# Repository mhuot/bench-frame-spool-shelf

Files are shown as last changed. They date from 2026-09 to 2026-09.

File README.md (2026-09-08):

# Bench Frame Spool Shelf

**[Project site &rarr; mhuot.github.io/bench-frame-spool-shelf](https://mhuot.github.io/bench-frame-spool-shelf/)**

Filament spool storage that hangs on the slotted uprights of a steel bench
frame. Mine is an Ergotron LAN Organizer 3000. Two printed brackets hook
into the slotted DuraFrame uprights and carry two parallel rods. Spools rest in the valley between the rods. Lift one straight out,
drop the next one in, nothing else moves. A spool in the cradle rolls
freely, so it feeds without a fight. No drilling and no hardware. The
brackets hook in the same way Ergotron's own shelves do.

The rods are 1" schedule 40 PVC by default. Wooden dowels, aluminium pipe
and conduit all work too. More on that below.

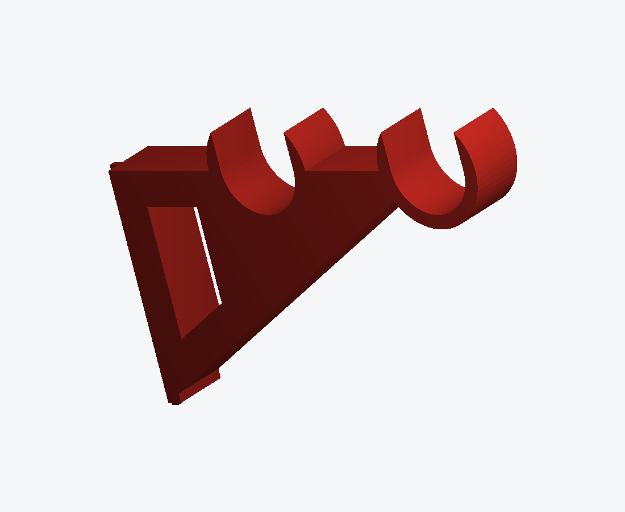
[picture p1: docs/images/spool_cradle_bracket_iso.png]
Spool cradle bracket


## The desk

In the 1990s it felt like every NOC and data center, at least the ones near
me, had furniture from [Ergotron](https://www.ergotron.com/) in
[Eagan, Minnesota](https://en.wikipedia.org/wiki/Eagan,_Minnesota). The desks
matched the look those rooms had and the job they did.

The one I have sat in a data center with a row of computers on it. They ran
the small ISP my employer operated. I picked it up when the company
liquidated, after they were no more. The slotted uprights are the same ones
that held their shelves, which is why nothing here needs a drill.

## Parts

| File | What it is |
|---|---|
| `exports/slot_gauge.stl` | **Print this first.** Just the hook plate. It tells you whether the hooks fit your upright before you spend four hours on a bracket. |
| `exports/saddle_coupon.stl` | **Print this second.** An 8 mm slice of the arm tip with both rod pockets. Drop your actual rod in and see if it seats. About 12 cm³. |
| `exports/spool_cradle_bracket.stl` | The bracket. Two per shelf level. It is symmetric, so there is no left or right. |
| `exports/rod_end_cap.stl` | Press-fit cap for the rod ends. The 42 mm flange stops a rod walking out of its saddle, and four crush ribs on the 24 mm stem grip the pipe bore. Sized for a bore I measured at 30 mm. The schedule 40 spec says 26.6 and was wrong for my pipe. Measure yours, set `PIPE_INNER_DIAMETER` in `scripts/build_rod_end_cap.py`, and print one before printing four per level. Flange down, no supports. |
| `exports/rod_label_clip.stl` | Snap-on label clip. A C-ring snaps onto a rod from below and slides along to sit under its spool. The 58 x 29 mm face takes a 1" x 2-1/8" adhesive label and hangs just past plumb, aimed at someone looking up at a rod above their head. That is `PADDLE_ANGLE_DEG = 100`. A shelf below eye level wants about 50. The face is flush with one side of the 20 mm ring, and the ring is that wide so the offset label does not cock the clip on the rod. One per spool, printed on the flat side (rotate 90° about X), no supports. Eight fit a MINI bed. |
| `cad/*.step`, `cad/*.f3d` | The same parts as CAD, written by the same build run as the STLs. |

## Check the fit before printing brackets

I measured the slots by hand. 3/4" tall, 1" vertical pitch, about 1/8"
wide. Each upright has one column of slots. The double track at the
middle of a 60" module is just the two joined frames' columns sitting side
by side. So the bracket hooks one column with a single centred blade
column, four rows tall, and mounts on any upright.

The first gauge pinched before it seated. Paint and the burr on a punched
slot are worth a millimetre no drawing mentions. The throat went from 2.8
to 3.8 mm, the lips got lead-in chamfers, and the second gauge sat flush.
Your uprights may differ from mine, so the gauge is still the first thing
to print.

1. Print `slot_gauge.stl` flat on its side and hook it into the upright.
   The blades should enter the slots, drop about 14 mm and sit flush with
   no rock. If it binds or rattles, edit `SLOT_WIDTH` or
   `FACE_METAL_THICKNESS` at the top of `scripts/build_rod_bracket.py`,
   rebuild, print again.
2. Print `saddle_coupon.stl` and drop your rod stock into both pockets. It
   should seat fully and lift out without force. If not, adjust
   `ROD_OUTER_DIAMETER` or `SADDLE_CLEARANCE`.
3. When both pass, print two brackets.

## Geometry

- The rod axes sit 70 mm and 150 mm out from the upright face, at the same
  height. A 200 mm spool resting on both rods touches them about 20°
  either side of plumb. Deep enough that it stays put, shallow enough to
  lift out one-handed. The back of the spool clears the upright by about
  10 mm.
- A resting spool's top sits about 285 mm above the bracket's bottom edge.
  Leave 12" of frame above the mounting slots.
- On the 30" DuraFrame (10-063-100) the upright centres are about 28"
  apart. Cut rods to 29.5" (750 mm) so they span both saddles fully.
- Nothing holds the rods down, because nothing ever pulls them up. Spools
  press them into the saddles and get lifted off, never with them.
  Sideways is a different story. That is what the end caps are for. Their
  crush ribs grip the bore and the flange is wider than the saddle, so a
  rod cannot walk out while you shove spools around. No glue.
- The bracket is 24 mm wide, narrower than the 1" gap between the two
  slot columns at the module centre, so both bays can carry cradles at the
  same height without the middle brackets colliding.

## Rods, sag and cost

One level holds about 12 kg. That is two brackets at about 6 kg each with
roughly 2x structural margin, so a full row of nine 1 kg spools, or count
3 kg spools by weight. Rod strength is never the limit. PVC runs at about
2 MPa against a 50 MPa allowable. Stiffness is the limit, because a rod
that sags forms a shallow valley and the spools slowly roll toward the
middle of it.

Sag below is per rod at full load, about 5.6 kg over the 711 mm span. Cost
is per level, two 29.5" rods, Home Depot, September 2026.

| Rod | Sag | Fits the stock 34.2 mm pocket? | Cost per level |
|---|---|---|---|
| 1" sch 40 PVC (default) | ~2.4 mm, creeping to 4-6 mm over months | yes | ~$5 (10 ft makes 4 rods) |
| 1" sch 40 aluminium pipe | ~0.1 mm, no creep | yes, same 33.4 mm OD as PVC | ~$32 ($48 for 8 ft, 3 rods) |
| 1-1/4" hardwood dowel | ~0.4 mm | close, 2.5 mm of play, fine | ~$10 |
| 1" hardwood dowel | ~1.0 mm | no, set `ROD_OUTER_DIAMETER = 25.4` | ~$6 |
| 3/4" EMT steel conduit | ~0.25 mm | no, set `ROD_OUTER_DIAMETER = 23.4` | ~$5 (10 ft makes 4 rods) |
| 1" EMT steel conduit | ~0.1 mm | no, set `ROD_OUTER_DIAMETER = 29.5` | ~$7 |

Start with PVC. It is fine, and the saddles are open, so you can swap rods
later without reprinting anything. Aluminium pipe is the nicest upgrade
because it drops straight in, but it costs six times what EMT does for a
sag difference of 0.15 mm that nobody will ever see. EMT is the stiffness
per dollar winner and only costs a pocket rebuild, which is one constant
and a saddle coupon reprint. Whatever you pick, deburr the cut ends. Spool
flanges bump the rod ends now and then while loading.

## Printing

- Brackets lie on their flat side, rod axes vertical in the slicer, so the
  layer planes line up with the load. Do not print one standing up. That
  puts a layer seam across every hook lip.
- ASA if your printer is enclosed. PETG otherwise, and it is completely
  adequate. The hooks live under constant tension, so what matters is
  creep and brittle fracture. ASA creeps less than PETG over months and
  stays ductile. PLA creeps too much. Carbon fibre blends are stiff but
  brittle in exactly the thin blade sections that must not snap. The
  180 mm bracket fits a 250 x 220 bed on its side with room to spare.
- Four or more perimeters, 40% infill or more.
- Load rating is about 6 kg per bracket. A full level is about 10 kg
  across two brackets. At that load the top hook row sees about 90 N of
  tension, roughly a 2x margin in PETG.
- End caps in ASA or PETG, flange down, no supports. The ribs are the
  press fit, so give them three or more walls rather than trusting infill.
- Label clips in PETG. They carry a label, not a load. 0.2 mm layers and
  three perimeters, so the 2.4 mm ring wall is solid and the snap cannot
  split along a gap-fill seam. Flat side down, no supports, brim optional.
  They snap over the rod from below with a few newtons of push and slide
  freely. Mine came off a MINI and a Core One, both in Prusament PETG.

## Rebuilding

Fusion 360 has to be running with its MCP server on `127.0.0.1:27182`.
Then

```sh
python3 scripts/run_in_fusion.py scripts/build_rod_bracket.py                  # bracket
python3 scripts/run_in_fusion.py scripts/build_rod_bracket.py --variant gauge
python3 scripts/run_in_fusion.py scripts/build_rod_bracket.py --variant coupon
python3 scripts/run_in_fusion.py scripts/build_rod_end_cap.py             # rod end cap
python3 scripts/run_in_fusion.py scripts/build_rod_label_clip.py          # label clip
```

Each run rebuilds the part inside its saved document in the "LAN Spool
Shelf" Fusion cloud project, which it creates if needed. It probes the
geometry numerically and fails loudly if any probe misses. Then it writes
the STL, STEP and F3D in the same run, so they cannot drift apart, and
saves a new version of the Fusion document with the key dimensions in the
description. The model's history lives in Fusion's version list as well
as in git.

Every document carries a user parameter table that mirrors the script
constants, and every one of those parameters drives geometry. The build
fails if one stops doing so. That makes them safe to edit live in Fusion.
The hook profile sketch is fully constrained against `hookThroat`, which
is the expression `faceMetalThickness + 1.8 mm`, plus `hookNeckHeight`,
`hookLipThickness`, `hookLipDrop`, `hookLipChamfer` and `topHookNeckTop`.
The rows are a rectangular pattern driven by `hookRows` times
`slotPitchVertical`.

A scripted rebuild regenerates the document from the script, so a hand
edit you want to keep has to go back into the script. The build refuses to
overwrite a document whose latest save is a hand edit with changed
geometry, so you cannot lose one by accident. Sanity-check a mesh
afterwards with

```sh
.venv/bin/python scripts/check_stl.py exports/spool_cradle_bracket.stl <mm3 from build output>
```

The Ergotron order guide (870-03-006) has frame widths and capacities but
no slot geometry, hence the ruler. It is Ergotron's document, so it is
not in this repo. If you have a copy, keep it at
`docs/03-006_obsolete.pdf`, which is gitignored.

## License

MIT, see `LICENSE`. Print them, sell them, remix them. A link back is
appreciated.

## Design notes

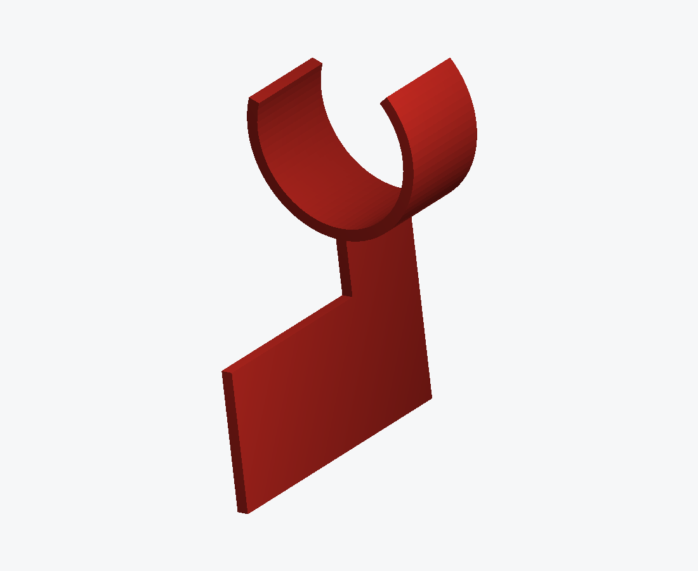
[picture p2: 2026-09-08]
docs/images/rod_label_clip_iso.png

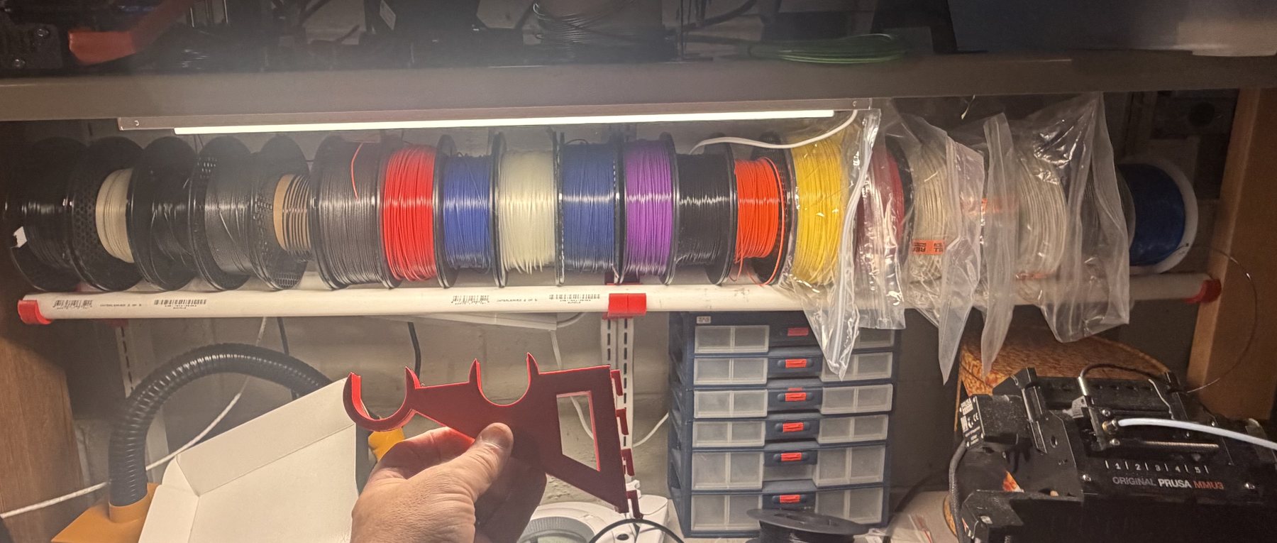
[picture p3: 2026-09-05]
docs/images/shelf-loaded.jpg

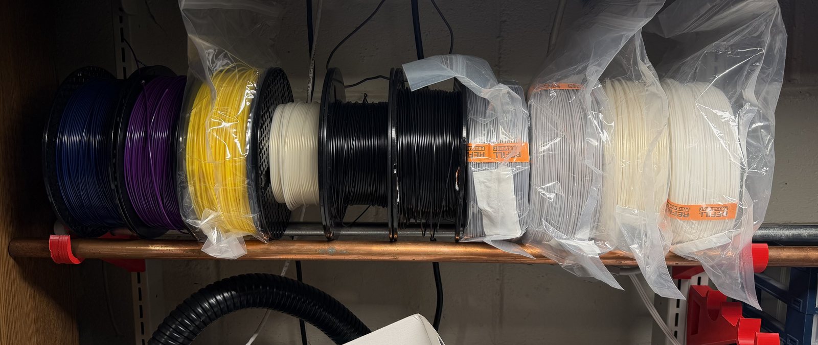
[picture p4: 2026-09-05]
docs/images/shelf-prototype.jpg

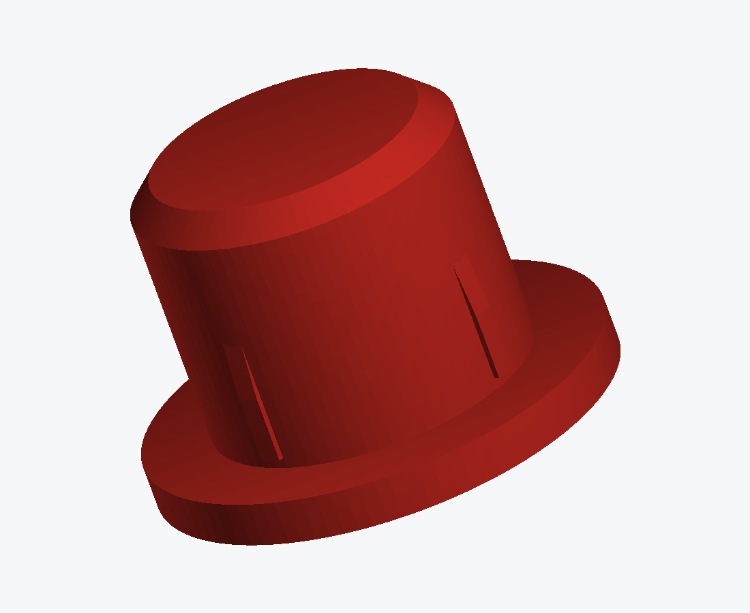
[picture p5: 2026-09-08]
docs/images/rod_end_cap_iso.png

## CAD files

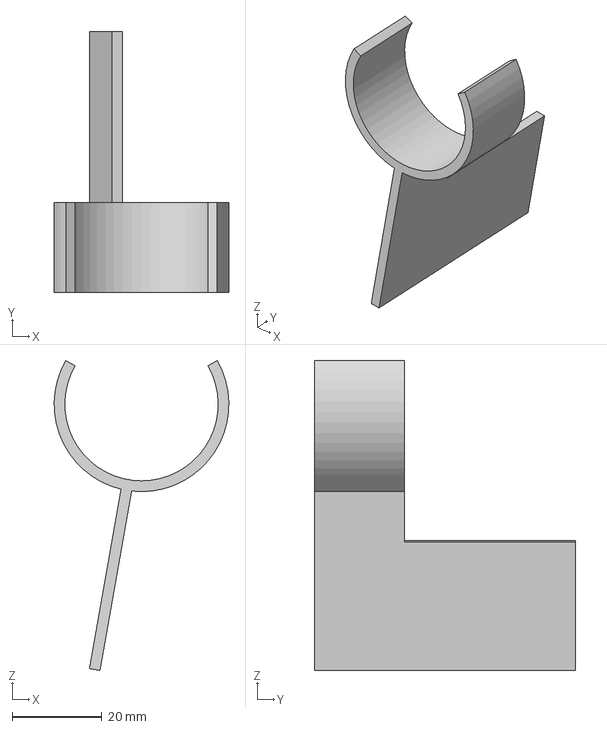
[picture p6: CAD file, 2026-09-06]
cad/rod_label_clip.step
38.9 x 58.0 x 69.0 mm

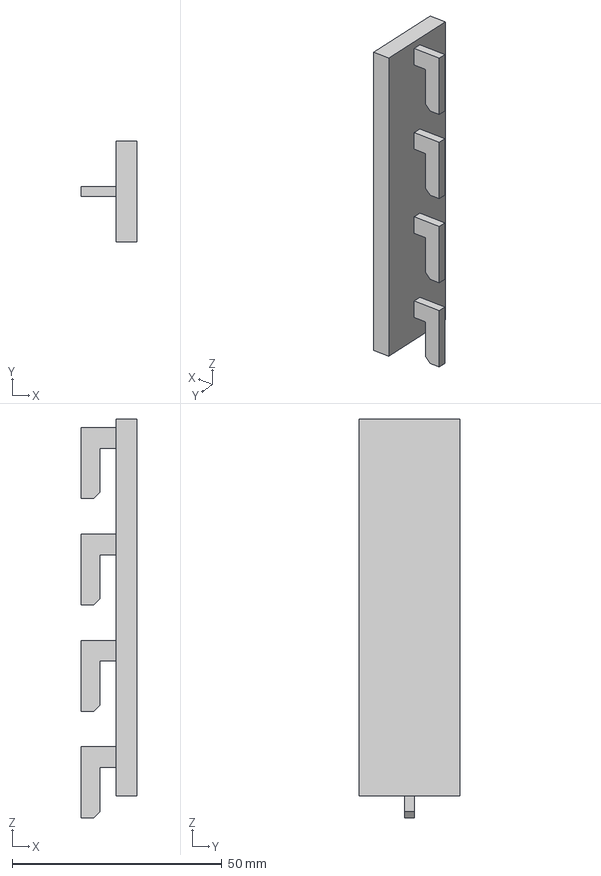
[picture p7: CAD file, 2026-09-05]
cad/slot_gauge.step
13.3 x 24.0 x 95.2 mm

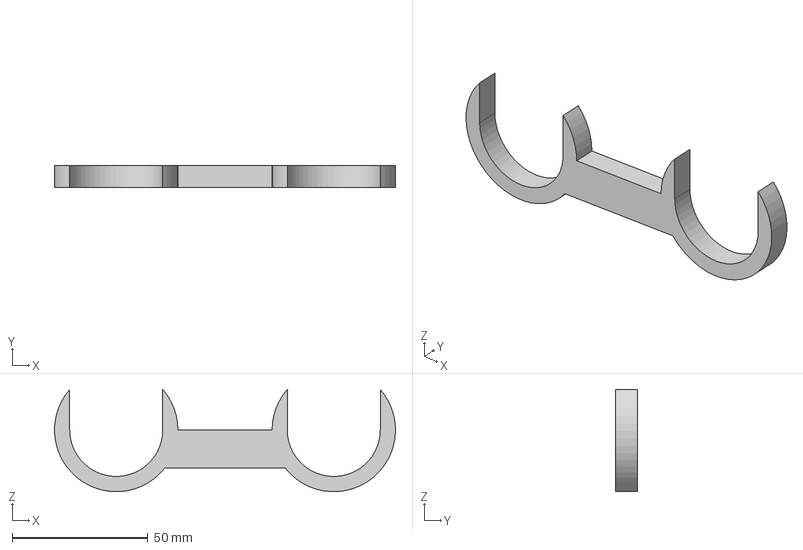
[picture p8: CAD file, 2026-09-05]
cad/saddle_coupon.step
125.4 x 8.00 x 37.6 mm

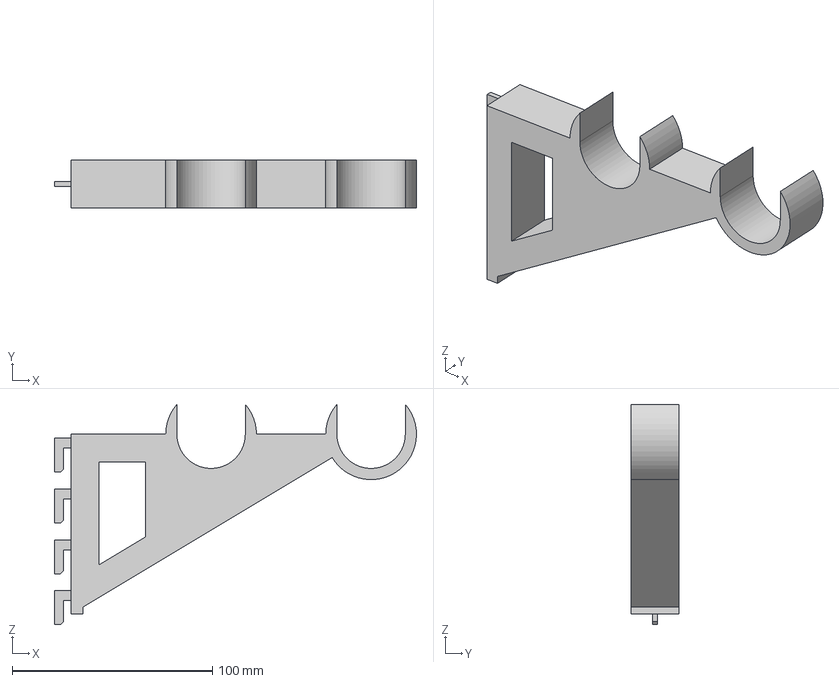
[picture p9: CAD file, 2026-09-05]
cad/spool_cradle_bracket.step
181.0 x 24.0 x 110.1 mm

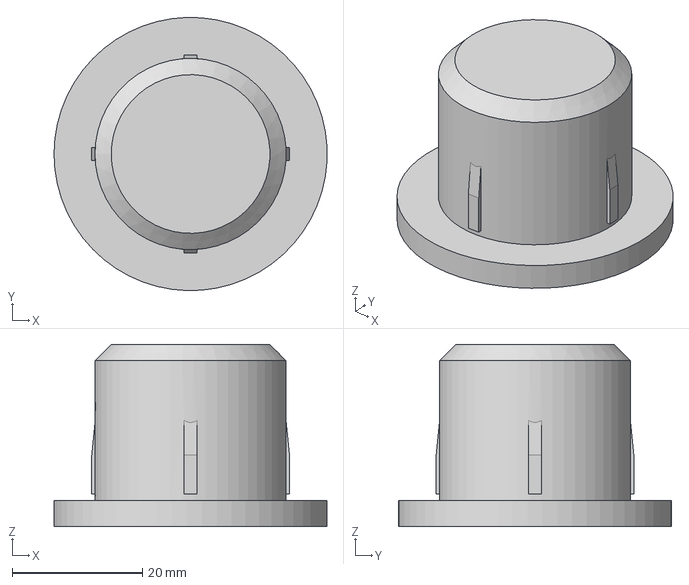
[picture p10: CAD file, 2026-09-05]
cad/rod_end_cap.step
42.0 x 42.0 x 28.0 mm

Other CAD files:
cad/rod_end_cap.f3d
cad/rod_label_clip.f3d
cad/saddle_coupon.f3d
cad/slot_gauge.f3d
cad/spool_cradle_bracket.f3d
exports/rod_end_cap.stl
exports/rod_label_clip.stl
exports/saddle_coupon.stl
exports/slot_gauge.stl
exports/spool_cradle_bracket.stl

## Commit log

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2026-09-02 Build gauge and bracket: verified geometry, STL/STEP/F3D exports, README
    Two Fusion API traps fixed en route: xZConstructionPlane sketch +y maps to
    model -Z, and Fusion's persistent interpreter keeps globals across MCP
    executions, so the variant override is appended after the script text
    rather than read via globals().get().
    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
    [slot_gauge.f3d, slot_gauge.step, slot_gauge.stl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]
2026-09-02 Two-pole cradle design: spools rest between rods, lift straight out
    Replaces the hang-on rod (which needed the pole pulled for every spool
    change). Rods at 70 and 150 mm standoff, both at plate-top height; a
    200 mm spool sits at ~20 deg contact half-angle and clears the upright
    by ~10 mm. Adds a saddle_coupon variant to test rod pocket fit; the
    slot_gauge still tests the hook fit.
    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
    [saddle_coupon.f3d, saddle_coupon.step, saddle_coupon.stl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]
2026-09-02 Single hook column: uprights have one slot track except at module centre
    The double track in the photos is the two joined frames meeting at the
    60" module centre; outside uprights carry one column. One centred blade
    column, four rows on a 90 mm plate, works on every upright. Lip bumped
    to 4.5 mm since one column now carries the whole moment.
    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
    [saddle_coupon.f3d, saddle_coupon.step, saddle_coupon.stl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]
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2026-09-02 Narrow bracket to 24 mm: single-column mount needs no wide plate
    Fits inside the 25.4 mm column gap at the module centre so both bays can
    mount at the same height, seats on one rail face, and saves ~40% material.
    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
    [slot_gauge.f3d, slot_gauge.step, slot_gauge.stl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]
2026-09-02 Parameterize, save, and version the Fusion documents
    Each variant now rebuilds into a named document in the 'LAN Spool Shelf'
    cloud project; every run saves a new Fusion version with a description of
    the key dimensions. Documents carry a user-parameter table: extrude
    widths are parameter-driven (safe to edit live), profile geometry stays
    script-driven and its parameters are marked reference-only.
    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
    [saddle_coupon.f3d, saddle_coupon.step, slot_gauge.f3d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]
2026-09-02 Widen hook throat to 3.8 mm after gauge fit test; rod material table
    First printed gauge entered the slots and dropped a few mm but pinched
    before seating: face metal + paint + punched-slot burr exceeds the bare
    2.0 mm assumption. Throat clearance now 1.8 mm with 1.5 mm lead-in
    chamfers on the lip bottoms. README gains a rod material/sag table —
    notably 1" sch 40 aluminum pipe matches PVC's OD and needs no rebuild.
    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
    [slot_gauge.f3d, slot_gauge.step, slot_gauge.stl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]
2026-09-02 README: rod material/sag/cost table (missed its anchor in prior commit)
    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
2026-09-03 Parameter-drive the hook stack: constrained profile + row pattern
    The hook profile sketch is now fully constrained and dimensioned against
    user parameters (hookThroat is the expression faceMetalThickness +
    1.8 mm), extruded by hookTabWidth, and arrayed by a rectangular pattern
    driven by hookRows x slotPitchVertical. Verified live: hookRows=3 drops
    the bottom row and restoring returns the exact original body.
    Gauge fit test 2 passed on the real upright with the 3.8 mm throat.
    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
    [slot_gauge.f3d, slot_gauge.step, slot_gauge.stl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]
2026-09-04 Rod end cap as its own part: press-fit flange stops axial rod walk
    New scripts/build_rod_end_cap.py (standalone, per project convention of
    self-contained Fusion scripts): revolved flange 2 mm proud of the sch 40
    OD, 14 mm stem slipping the bore, four crush ribs via a circular pattern.
    Fully parameter-driven (constrained profile + rib sketches, endCapRibCount
    pattern). Saved as 'Rod End Cap' in the Fusion project. Print four per
    level, flange down.
    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
    [rod_end_cap.f3d, rod_end_cap.step, rod_end_cap.stl]
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2026-09-04 End cap for measured pipe: 30 mm bore, 42 mm flange, 28 mm tall
    The real pipe's bore measures ~30 mm, not the 26.6 mm sch 40 spec — the
    first printed caps are scrap. Flange grown to 42 mm (still seats flat
    inside the saddle wall's 45.4 mm face) and stem lengthened to 24 mm for
    deeper grip.
    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
    [rod_end_cap.f3d, rod_end_cap.step, rod_end_cap.stl]
2026-09-04 End cap ribs become long wedges: easy start, grip only at the end
    Fit feedback: caps a little too snug from the first contact. Ribs now
    rise from flush at the tip to full crush height over the last 6 mm near
    the flange (endCapRibGripLength), and the tip chamfer grows to 2.5 mm —
    insertion starts loose and self-centred, full grip engages only as the
    flange seats.
    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
    [rod_end_cap.f3d, rod_end_cap.step, rod_end_cap.stl]
2026-09-05 Snap-on rod label clip: one per spool, face fits 12 mm label tape
    C-ring wraps the bottom 220 deg of the rod (the mouth clears the spool's
    resting contact point), snaps on from below with ~1.4 mm interference,
    and slides along the rod. The paddle hangs at -50 deg so the 55 mm label
    face reads at a 40 deg upward tilt. Built sign-proof: annulus + symmetric
    fan cut, no sketch arcs.
    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
    [rod_end_cap.f3d, rod_end_cap.step, rod_label_clip.f3d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]
2026-09-05 Label face sized for 1" x 2-1/8" adhesive labels (58 x 29 mm)
    Fits whole labels with margin while still clearing the ~70 mm spool
    pitch, so every spool can carry a clip at any packing density.
    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
    [rod_label_clip.f3d, rod_label_clip.step, rod_label_clip.stl]
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2026-09-05 Add project site, MIT license, and the GLB asset builder
    docs/ is a GitHub Pages site: the hero photo of the built shelf, an
    interactive model-viewer assembly built from the shipped STLs by
    scripts/build_web_assets.py, part renders, and the rod/sag/cost and
    print-time tables. Untracks .DS_Store and Ergotron's order-guide PDF
    (their document, not ours to redistribute).
    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
2026-09-05 Fix GLB orientation: glTF is Y-up, the CAD scene is Z-up
    The shelf rendered standing on end with the rods vertical — a plausible
    looking render of the wrong thing. trimesh does not convert handedness on
    export, so the scene now rotates -90 about X before writing the GLB, and
    the camera orbits to a three-quarter view across the rods.
    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
2026-09-05 Make every parameter actually drive geometry, with real units
    The Rod Label Clip's mouth was a hardcoded sketch number sitting beside a
    mouthHalfAngleDeg that Fusion had stored in millimetres. An audit across
    all six documents found that was the tip of it: 13 of 23 bracket
    parameters, 6 of 10 clip parameters and the whole pegboard plate/bolt
    group drove nothing at all.
    Now: every sketch is dimensioned against parameters (plate, arm, saddles,
    drop-in openings, lightening cutout, coupon chord, ring, mouth wedge,
    paddle strips), angles carry deg and counts are unitless, each variant
    declares only the parameters it uses, stale parameters are dropped on
    rebuild, and each build fails if a declare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
    [rod_end_cap.f3d, rod_end_cap.step, rod_label_clip.f3d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]
2026-09-05 Adopt the user's mouth construction, recovered from document v3
    My rebuild had overwritten manual edits with a triangle plus a symmetry
    constraint. Version 3 of the document ('User Saved') shows what was
    actually built: a quadrilateral apexed on the clip centre, its far side
    meeting at a point carried on a vertical centre construction line, with
    each leg dimensioned by its own angular dimension to that line.
    The script now reproduces that construction. It also dimensions all three
    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
    [rod_label_clip.f3d, rod_label_clip.step]
2026-09-05 Label clip: derive the stem and face radii from the ring parameters
    stemStartRadius was a fixed 16 mm while the bore radius is computed from
    rodOuterDiameter and clipClearance (17.05 mm), so the stem already reached
    1 mm into the bore and got worse whenever the clearance was edited. The
    three radii are now derived user parameters: the stem starts mid ring
    wall, runs stemLength past the outer wall, and the face adds faceHeight.
    Editing the rod, clearance or wall moves the stem with the ring.
    Two new probes check the bore is clear and the stem is joined along the
    paddle angle itself; the old bore probe only looked straight down and
    missed the intrusion. Verified live at 0.2, 2 and 4 mm cleara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
    [rod_label_clip.f3d, rod_label_clip.step, rod_label_clip.stl]
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2026-09-06 Document the operating model: Fusion is the working surface
    Mike works in Fusion; the scripts regenerate documents from scratch, which
    makes a hand edit something a rebuild destroys. CLAUDE.md now states the
    rule that follows from that: never rebuild over an edit, treat an edit as a
    proposal to fold into the script, and confirm the rebuild by matching the
    document's volume.
    The guard now compares geometry rather than authorship — a plain save with
    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
    [rod_label_clip.f3d, rod_label_clip.step]
2026-09-06 Label clip: aim the face at a viewer below the rod, print without support
    The rod now sits at the top of the rails, about 76" up, so a 72" viewer
    looks up at the label by 10 to 20 degrees. paddleAngleDeg goes from 50 to
    100: the face hangs just past plumb, lower edge leaned back, aimed at that
    sightline instead of 50 degrees off it.
    The strip construction could not go there: it pinned corners with unsigned
    distances from the origin, and past about 85 degrees a corner crossed the
    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
    [rod_label_clip.f3d, rod_label_clip.step, rod_label_clip.stl]
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2026-09-06 Label clip: 20 mm ring so the offset label hangs level
    With the face flush to one side of the ring, its weight cocks the ring on
    the rod until the ring's edges touch the pipe. The tilt limit is roughly
    clipClearance / clipWidth; at 9 mm the label hung about 3 degrees off
    level on the shelf. 20 mm halves that and shortens the moment arm, since
    the face stays flush with the wider ring. Same print footprint, no
    supports, about 3.4 g more filament. Fresh render and GLB.
    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
    [rod_label_clip.f3d, rod_label_clip.step, rod_label_clip.stl]
2026-09-06 Retrofit collar: widen first-run 9 mm label clips to 20 mm on the rod
    New part and document "Rod Label Collar", built by
    scripts/build_rod_label_collar.py. It snaps over the rod and an existing
    clip ring from below: a revolved pocket with 45 degree ledges swallows
    the ring, a slot cut on a plane at the stem angle passes the stem and
    captures it sideways, and the collar bears on the rod 20 mm end to end,
    the same lever the new clips have.
    One-sided on purpose: the clip sits under its spool with the label toward
    the spool's centre, so the collar puts almost all its width on the label
    side and only 3.7 mm toward the neighbouring spool. The band's outer step
    on the label side is a revolved 45 d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
    [rod_label_collar.f3d, rod_label_collar.step, rod_label_collar.stl]
2026-09-07 Drop the retrofit collar
    The first-run 9 mm clips will be replaced by the 20 mm design rather than
    retrofitted, so the collar part, its exports, render and documentation go.
    The Fusion document "Rod Label Collar" is left in the cloud project for
    now; the script that built it is in history at 07ddb4c.
    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
    [rod_label_collar.f3d, rod_label_collar.step, rod_label_collar.stl]
2026-09-07 Site model: put the spool flanges at the spool's sides
    trimesh builds cylinders on the Z axis, but the flanges were offset along
    Y before the spool was rotated onto the rods, which left both flanges at
    the spool's middle shifted up and down, and the core sticking out of the
    sides where the flanges should have been. Flanges and the wound filament
    are now annuli offset along the axis, and the core is a hollow tube flush
    with the flanges, so a spool reads as a spool from every angle. Assembly
    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
    [rod_label_clip_mouth60.stl]
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2026-09-07 Rewrite README and site prose in Mike's voice
    Same facts, plainer sentences. No em-dashes, colons or semicolons in the
    prose, shorter sentences, and a few more specifics. The site's label
    clip print row now matches the 20 mm clip, and the sibling project link
    points at lan-skadis-mount, which is published.
    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
